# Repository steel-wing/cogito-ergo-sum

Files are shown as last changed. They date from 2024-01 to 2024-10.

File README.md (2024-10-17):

# clacken

clacken

*A short description of the keyboard/project*

* Keyboard Maintainer: [Carter Pollan](https://github.com/Carter Pollan)
* Hardware Supported: *The PCBs, controllers supported*
* Hardware Availability: *Links to where you can find this hardware*

Make example for this keyboard (after setting up your build environment):

    make clacken:default

Flashing example for this keyboard:

    make clacken:default:flash

See the [build environment setup](https://docs.qmk.fm/#/getting_started_build_tools) and the [make instructions](https://docs.qmk.fm/#/getting_started_make_guide) for more information. Brand new to QMK? Start with our [Complete Newbs Guide](https://docs.qmk.fm/#/newbs).

## Bootloader

Enter the bootloader in 3 ways:

* **Bootmagic reset**: Hold down the key at (0,0) in the matrix (usually the top left key or Escape) and plug in the keyboard
* **Physical reset button**: Briefly press the button on the back of the PCB - some may have pads you must short instead
* **Keycode in layout**: Press the key mapped to `QK_BOOT` if it is available

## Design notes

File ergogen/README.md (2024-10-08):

# BYU-IEEE-Keyboard-Project
This is the template for both the Ergogen file and the QMK firmware that the BYU IEEE club uses to create custom keyboards.

## Resources
### Websites
 - [Ergogen Unofficial](https://ergogen.cache.works/)
 - [Ergogen Official](https://ergogen.xyz/)
 - [QMK](https://qmk.fm/)
### Docs
 - [Ergogen Docs](https://docs.ergogen.xyz/)
 - [QMK Docs](https://docs.qmk.fm/#/)
### Guides
 - [Ergogen guide by FlatFootFox](https://flatfootfox.com/ergogen-introduction/)
### Tools
 - [Ergogen Auto Layout](https://pashutk.com/ergopad/)
 ## Ergogen
Ergogen is a platform that will take the dificult parts of designing a keyboard and gets you 90% of the way there with one web tool. You can use it to design a pcb, case, and face plate. One of the dificult things about it is that it recently updated to v4.0, which has breaking changes to the way it works, but the official docs has been mostly updated but isn't complete. To get a better understaning of ergogen and how to use it well read the [Ergogen guide by FlatFootFox](https://flatfootfox.com/ergogen-introduction/). This is a great introduciton to ergogen and how to use it to make a keyboard.
### Ergogen Auto Layout
This is a great tool to use if you are unsure of what a custom keyboard made for your hands even looks like. After using it you will get an idea of what a custom keyboard for you might look like. This is only supposed to be a visualization tool. When I tried to use it last I couldn't get it to output something Ergogen could read. The export button gave me a csv of the places I touched the screen.
### Case Design
Making a case is a little bit too complex for my liking. One thing I ran into trouble with is getting the 3D files that ergogen outputs into something that a slicer can use. I had to install npx to get this to work but after I did it worked like a treat.

`for i in ./*.jscad; do npx @jscad/cli@1 "$i" -of stla; done`

## QMK
QMK is the resource I used to program my keyboard. It is much easier to use than starting programing in C from scratch. That being said starting with the QMK docs can be really difficult as the documentaiton is not friendly to those who are new to it. What I recomend to get started is watch an into to QMK video on youtube, read the getting started seciton in the docs, them run `qmk new-keyboard` and it will walk you through the steps of how to build your firmware. That command will get you through a lot of the dificult early configuration challenges.
## Files
A description of the differnt files in the repository
### config.yaml
 - My Ergogen config file. It is my current code for makeing a keyboard in Ergogen.
### footprints
 - This is where I store any footprints I want to use that are not built into the Ergogen tool. Right now I have changed all of the footprints in some way so I am no longer using any stock Ergogen footprints.
### qmk_firmware
 - This is where I keep the qmk firmware that I use to program the keyboard. It isn't meant to be run in this repo. It is supposed to be copied to a fork of the qmk_firmware branch and ran from there.
### .gitignore
 - I don't want to update the output of my ergogen files so I ignore the output folder.
### .gitmodules
 - I use git modules to include the most up to date version of different footprints in my project.
### points_demo.yaml
 - This file is the yaml for the pointmap I made live in the IEEE club. It is a good example of using metatdata and points and a rather poor example of using units. It is not perfect and should not be used as the basis of a keyboard but rather an example of how to use the funcitons and paramaters of Ergogen.
### outlines_demo.yaml
 - This is another file generated from a live demonstration of how to use outlines in Ergogen. It has examples of many of the basic features of an ergogen

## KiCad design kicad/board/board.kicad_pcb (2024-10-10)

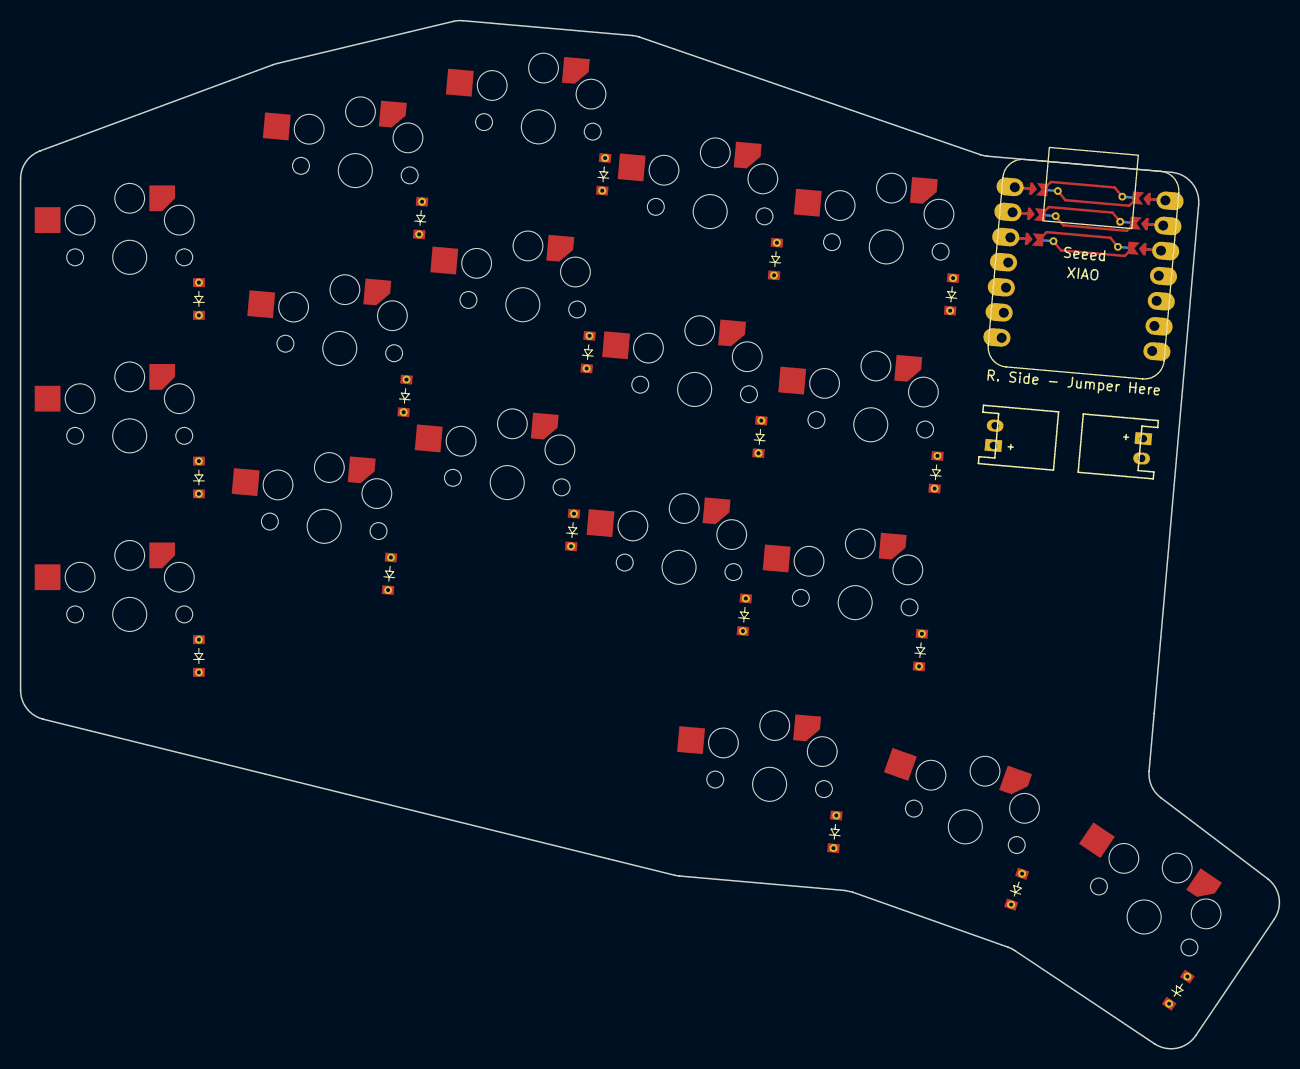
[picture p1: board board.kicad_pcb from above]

Board: 2 copper layers, 126.9 x 103.7 mm, 39 parts (0 on the bottom side), 29 nets.

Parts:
D1, D2, D3, D4, D5, D6, D7, D8, D9, D10, D11, D12, D13, D14, D15, D16, D17, D18: 1N914; reversable_diode
JST1, JST2: Conn_01x02; JST_angled
S1, S2, S3, S4, S5, S6, S7, S8, S9, S10, S11, S12, S13, S14, S15, S16, S17, S18: SW_Push_45deg; choc_switches
U1: xiao-ble-tht

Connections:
Col1: S1.1, S2.1, S3.1
Col2: S4.1, S5.1, S6.1
Col3: S7.1, S8.1, S9.1, S16.1
Col4: S10.1, S11.1, S12.1, S17.1
Col5: S13.1, S14.1, S15.1, S18.1
unnamed: D1.2 (A), S1.2
unnamed: D2.2 (A), S2.2
unnamed: D3.2 (A), S3.2
unnamed: D4.2 (A), S4.2
unnamed: D5.2 (A), S5.2
unnamed: D6.2 (A), S6.2
unnamed: D7.2 (A), S7.2
unnamed: D8.2 (A), S8.2
unnamed: D9.2 (A), S9.2
unnamed: D10.2 (A), S10.2
unnamed: D11.2 (A), S11.2
unnamed: D12.2 (A), S12.2
unnamed: D13.2 (A), S13.2
unnamed: D14.2 (A), S14.2
unnamed: D15.2 (A), S15.2
unnamed: D16.2 (A), S16.2
unnamed: D17.2 (A), S17.2
unnamed: D18.2 (A), S18.2
unnamed: JST1.1, JST2.1
unnamed: JST1.2, JST2.2
Row1: D3.1 (K), D6.1 (K), D9.1 (K), D12.1 (K), D15.1 (K)
Row2: D2.1 (K), D5.1 (K), D8.1 (K), D11.1 (K), D14.1 (K)
Row3: D1.1 (K), D4.1 (K), D7.1 (K), D10.1 (K), D13.1 (K)
Row4: D16.1 (K), D17.1 (K), D18.1 (K)

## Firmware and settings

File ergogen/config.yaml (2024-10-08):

metadata:
  engine: 4.1
  version: 2.0
  author: Carter Pollan
  contact: carter.pollan@gmail.com

units:
  kx: cx
  ky: cy - 7
  px: cx - 7
  py: ky
  ledy: -cx/2 + 3
  feet_rad: 3.25
  feet_offset: 1
  case_thickness: 1.5
  case_offset: .05
  case_trrs: 4

points:
  zones:
    matrix:
      key:
        padding: cy + 1
        spread: cx
      columns:
        pinky:
          key:
            col_net: P017
        ring:
          key:
            splay: -5
            origin: [-12, -19]
            stagger: 10
            col_net: P020
        middle:
          key:
            stagger: 6
            col_net: P022
        index:
          key:
            stagger: -7
            col_net: P024
        inner:
          key:
            stagger: -2
            col_net: P100
      rows:
        bottom:
          row_net: P106
        home:
          row_net: P104
        top:
          row_net: P011
    thumbfan:
      anchor:
        ref: matrix_inner_bottom
        shift: [-7, -19]
      columns:
        near:
          key:
            col_net: P022
        home:
          key:
            spread: 0
            splay: -14.5
            origin: [0, -80]
            col_net: P024
        far:
          key:
            spread: 0
            splay: -14.5
            origin: [0, -80]
            col_net: P100
      rows:
        thumb:
          row_net: P009

outlines:
  keys:
  - what: rectangle
    where: true
    size: [16.75, 16.75]
  board:
  - what: polygon
    operation: stack
    fillet: 3
    points:
    - ref: matrix_pinky_top
      shift: [-px, py]
    - ref: matrix_ring_top
      shift: [-cx/2, py]
    - ref: matrix_middle_top
      shift: [-cx/2, py]
    - ref: matrix_middle_top
      shift: [cx/2, py]
    - ref: matrix_inner_top
      shift: [cx/2, py]
    - ref: matrix_inner_top
      shift: [cx*4/2 - 5, py]
    - ref: matrix_inner_bottom
      shift: [cx*4/2 - 5,-cy/2]
    - ref: thumbfan_far_thumb
      shift: [-px+4,px]
    - ref: thumbfan_far_thumb
      shift: [px, py]
    - ref: thumbfan_far_thumb
      shift: [px, -py]
    - ref: thumbfan_home_thumb
      shift: [cy/2, -py]
    - ref: thumbfan_home_thumb
      shift: [-cy/2, -py]
    - ref: thumbfan_near_thumb
      shift: [cy/2, -py]
    - ref: thumbfan_near_thumb
      shift: [-cy/2, -py]
    - ref: matrix_pinky_bottom
      shift: [-px, -py]
  board_outer:
  - what: polygon
    operation: stack
    fillet: 3
    points:
    - ref: matrix_pinky_top
      shift: [-px, py]
    - ref: matrix_ring_top
      shift: [-cx/2, py]
    - ref: matrix_middle_top
      shift: [-cx/2, py]
    - ref: matrix_middle_top
      shift: [cx/2, py]
    - ref: matrix_inner_top
      shift: [cx/2 - 24, py + 6]
    - ref: matrix_inner_top
      shift: [cx*4/2 - 5, py + 6]
    - ref: matrix_inner_bottom
      shift: [cx*4/2 - 5,-cy/2]
    - ref: thumbfan_far_thumb
      shift: [-px+4,px]
    - ref: thumbfan_far_thumb
      shift: [px, py]
    - ref: thumbfan_far_thumb
      shift: [px, -py]
    - ref: thumbfan_home_thumb
      shift: [cy/2, -py]
    - ref: thumbfan_home_thumb
      shift: [-cy/2, -py]
    - ref: thumbfan_near_thumb
      shift: [cy/2, -py]
    - ref: thumbfan_near_thumb
      shift: [-cy/2, -py]
    - ref: matrix_pinky_bottom
      shift: [-px, -py]
  faceplateKeys:
  - what: rectangle
    where: true
    size: [14,14]
  faceplateOutline:
  - what: polygon
    operation: stack
    fillet: 3
    points:
    - ref: matrix_pinky_top
      shift: [-px, py]
    - ref: matrix_ring_top
      shift: [-cx/2, py]
    - ref: matrix_middle_top
      shift: [-cx/2, py]
    - ref: matrix_middle_top
      shift: [cx/2, py]
    - ref: matrix_inner_top
      shift: [cx/2, py]
    - ref: matrix_inner_top
      shift: [cx/2, py]
    - ref: matrix_inner_home
      shift: [cx/2, -10]
    - ref: matrix_inner_home
      shift: [cx*4/2 - 5,-10]
    - ref: matrix_inner_bottom
      shift: [cx*4/2 - 5,-cy/2]
    - ref: thumbfan_far_thumb
      shift: [-px+4,px]
    - ref: thumbfan_far_thumb
      shift: [px, py]
    - ref: thumbfan_far_thumb
      shift: [px, -py]
    - ref: thumbfan_home_thumb
      shift: [cy/2, -py]
    - ref: thumbfan_home_thumb
      shift: [-cy/2, -py]
    - ref: thumbfan_near_thumb
      shift: [cy/2, -py]
    - ref: thumbfan_near_thumb
      shift: [-cy/2, -py]
    - ref: matrix_pinky_bottom
      shift: [-px, -py]
  faceplate:
  - name: faceplateOutline
  - operation: subtract
    name: faceplateKeys
  microcontroller_cut_out:
  - what: polygon
    operation: stack
    fillet: 3
    points:
    - ref: matrix_inner_top
      shift: [cx*2, py*2]
    - ref: matrix_inner_top
      shift: [cx/2, py*2]
    - ref: matrix_inner_home
      shift: [cx/2, -10]
    - ref: matrix_inner_home
      shift: [cx*4/2, -10]
  case_inner:
  - name: board
    expand: case_offset
  case_inner_shelf:
  - name: case_inner
    expand: -1
  case_shelf:
  - name: case_inner
  - -case_inner_shelf
  case_outer:
  - name: board_outer
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

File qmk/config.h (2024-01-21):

// Copyright 2024 Carter Pollan (@Carter Pollan)
// SPDX-License-Identifier: GPL-2.0-or-later

#pragma once

/*
 * Feature disable options
 * These options are also useful to firmware size reduction.
 */

 /* Serial communication */
#define SERIAL_USART_FULL_DUPLEX
#define SERIAL_USART_TX_PIN GP6 // Left: GP3 Right: GP6
#define SERIAL_USART_RX_PIN GP29 // Left: GP4 Right: GP29

/* Defines handedness EEPROM */
#define EE_HANDS
/*
add these flags when flashing to set the handedness

-bl uf2-split-left
-bl uf2-split-right*/

#define MATRIX_COL_PINS_RIGHT { GP4, GP3, GP28, GP27, GP26 }
#define MATRIX_ROW_PINS_RIGHT { GP2, GP1, GP0, GP7 } //{ GP2, GP1, GP0, GP7 }

/* disable debug print */
//#define NO_DEBUG

/* disable print */
//#define NO_PRINT

/* disable action features */
//#define NO_ACTION_LAYER
//#define NO_ACTION_TAPPING
//#define NO_ACTION_ONESHOT

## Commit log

2024-01-18 init of broken code
    [config.h]
2024-10-08 init of board
    [board.kicad_pcb]
2024-10-08 added relevent kicad files to gitignore
2024-10-10 init of footprints
2024-10-10 updated pcb
    [board.kicad_pcb]
